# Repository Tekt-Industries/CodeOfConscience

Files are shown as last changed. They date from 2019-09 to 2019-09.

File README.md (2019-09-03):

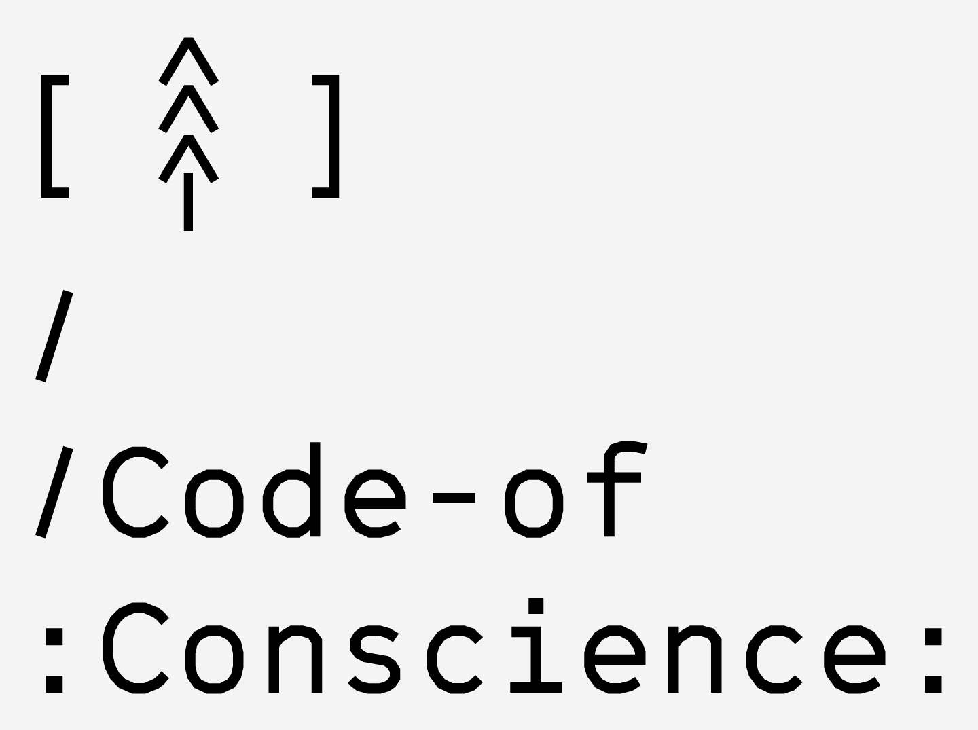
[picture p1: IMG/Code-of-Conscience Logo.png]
Tekt Industries


License (https://www.gnu.org/licenses/gpl-2.0.html)

## Summary

The Code of Conscience hardware platform was created as a call-to-action for partners to co-develop a low-cost, mass-manufacturable asset tracking system, designed specifically for the heavy machinery industry, including earth-moving equipment. 

Asset tracking telemetry systems are not a new technology and can be found in some modern heavy machinery but we currently don't use the data from these systems to protect ecosystems or provide transparency around their use. Older machinery is also unlikely to include asset tracking technology and can therefore slip through the cracks.  

The hardware platform itself is a low-component count cellular and GPS enabled IoT gateway, designed around the Nordic Semiconductor nRF9160 module, created to help start finding solutions to the world-wide problem of deforestation by directly raising awareness through remote monitoring of earth moving machinery potentially working illegally within protected rainforest areas.

The works shared here provide the full collection of schematic and PCB design files intended as a starting point for those individuals and organisations who wish to build smart devices that can ultimately be used to track and prevent rain-forest harvest and destruction outside the designated areas. 

These open-source designs can also be extended and customised to do more than asset tracking. For instance, the platform could be modified to detect fire within the worlds protected forests as an early warning system.

We encourage you to take up this call-to-action and create technology that changes our world for the better. 

## License

This documentation contains information which is provided AS IS, without attribution of liability or warranty under the GNU GPL v2.0 License - Open Source and permissive for commercial use, modification, distribution, and private use.

## Contributors

A dedicated team of engineers at [Tekt Industries](https://www.tektindustries.com), an international product design house based in  Melbourne, Australia brought together their years of experience within the IoT hardware development space to help create the initial hardware platform so that it may be shared with the world and grow from here.

We have been inspired by [AKQA](https://www.akqa.com), who heralded the call to action, crafted sample code, and provided the basis for the graphics that adorn the hardware platform.

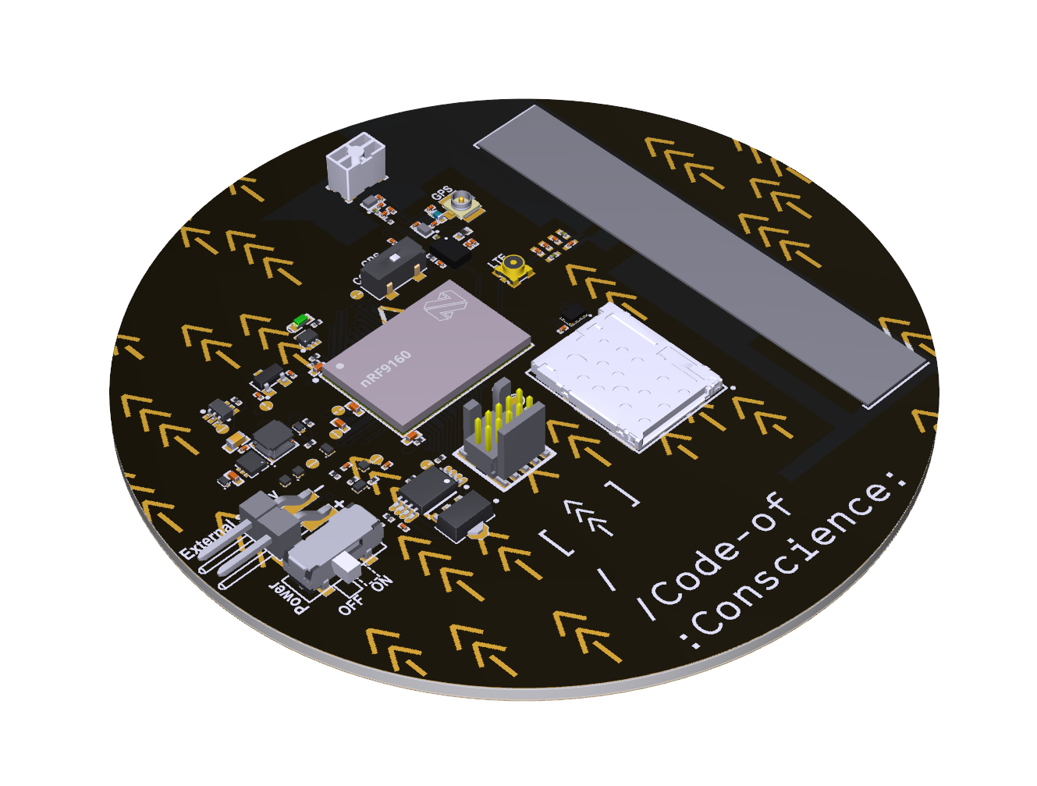
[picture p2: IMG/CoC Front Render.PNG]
PCB


[PCB]: https://github.com/Tekt-Industries/CodeOfConscience/blob/master/IMG/CoC%20Front%20Render.PNG "Tekt Industries"

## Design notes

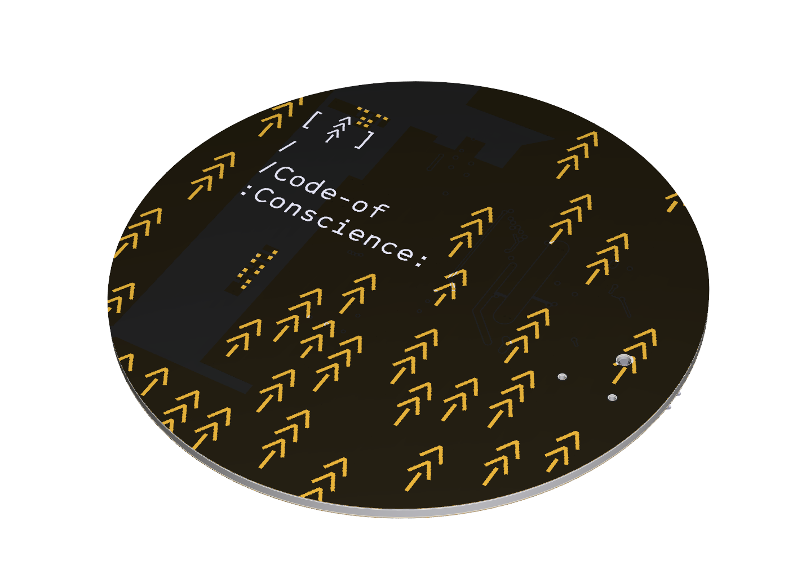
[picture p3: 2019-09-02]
IMG/CoC Back Render.PNG

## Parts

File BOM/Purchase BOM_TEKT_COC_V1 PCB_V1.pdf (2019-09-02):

| | Purchase BOM Source Data From: | | TEKT_COC_V1 PCB.PrjPCB | | | Note:
| | Project: | | TEKT_CoC_V1
| | Variant: | | None
| | Report Date: | 2/09/2019 | 5:41 PM
| | Print Date: | 02-Sep-19 | 6:32:28 PM
Quantity | Designator | Value | Comment | Description | Manufacturer | Manufacturer Part No. | Supplier | Supplier Part No. | Footprint | Reference
1 | A1 | 1462350001 | 1462350001 | ANTENNA MOLDED 1.575GHZ GPS | Molex | 1462350001 | Digi-Key | WM15009CT-ND | 1462350001 | TEKT_CoC_V1: A1
1 | A2 | P822601 | P822601 | ANTENNA PRESTTA OCTABAND LTE | Ethertronics | P822601 | Digi-Key | 939-1057-1-ND | P822601 | TEKT_CoC_V1: A2
4 | C1, C9, C15, C23 | 100pF | 100pF | Capacitor, NP0, ±2% | Murata Electronics North America | GRM0335C1E101JA01D | Digi-Key | 490-3160-1-ND | CAPC0603X03L_C | TEKT_CoC_V1: C1, C9, C15, C23
6 | C2, C8, C16, C21, C25, C26 | 100nF | 100nF | Capacitor, X5R, ±10% | Murata Electronics North America | GRM033R61C104KE84D | Digi-Key | 490-9985-1-ND | CAPC0603X03L_C | TEKT_CoC_V1: C2, C8, C16, C21, C25, C26
2 | C3, C4 | 39pF | 39pF | Chip Cap 0201 | Murata Electronics North America | GRM0335C1H390JA01D | Digi-Key | 490-11326-1-ND | CAPC0603X03L_C | TEKT_CoC_V1: C3, C4
5 | C5, C17, C18, C19, C22 | 4.7µF | 4.7µF | Capacitor, X5R, ±20% | Murata Electronics North America | ZRB15XR61A475KE01D | Digi-Key | 490-13252-1-ND | CAPC1005X04L | TEKT_CoC_V1: C5, C17, C18, C19, C22
1 | C6 | 4.7pF | 4.7pF | Chip Cap 0201 | Murata Electronics North America | GRM0335C1H4R7CA01D | Digi-Key | 490-6130-1-ND | CAPC0603X03L_C | TEKT_CoC_V1: C6
4 | C7, C12, C13, C14 | N.C. | N.C. | Not mounted | | | | | CAPC0603X03L_C | TEKT_CoC_V1: C7, C12, C13, C14
1 | C10 | 3.5pF | 3.5pF | Chip Cap 0201 | Taiyo Yuden | UMK063CG3R5CTHF | Digi-Key | 587-5326-1-ND | CAPC0603X03L_C | TEKT_CoC_V1: C10
1 | C11 | 33pF | 33pF | Chip Cap 0201 | Murata Electronics North America | GRM0335C1H330JA01D | Digi-Key | 490-6126-1-ND | CAPC0603X03L_C | TEKT_CoC_V1: C11
1 | C20 | 10nF | 10nF | Capacitor, X7R, ±10% | Murata Electronics North America | GRM033R61E103KA12D | Digi-Key | 490-7194-1-ND | CAPC0603X03L_C | TEKT_CoC_V1: C20
1 | C24 | 10µF | 10µF | Capacitor, 0603, 25V, X5R | Murata Electronics North America | ZRB18AR61E106ME01L | Digi-Key | 490-10991-1-ND | CAPC1608X06L | TEKT_CoC_V1: C24
2 | C27, C28 | 1.0µF | 1.0µF | Capacitor, X5R, ±10% | Samsung Electro-Mechanics | CL03A105KP3NSNC | Digi-Key | 1276-6795-1-ND | CAPC0603X03L_C | TEKT_CoC_V1: C27, C28
1 | D1 | CM1402 | CM1402 | EMI Network Filter Arrays SIM CARD EMI FILTER WITH ESD PROTECTION | ON Semiconductor | CM1402-03CP | Digi-Key | CM1402-03CPOSTR-ND | CM1402 | TEKT_CoC_V1: D1
2 | D2, D3 | NSR0620P2T5G | NSR0620P2T5G | 20V schottky barrier diode, Vf 350 mV @ 100 mA, Ir 2.0 µA @ 10 V, If 500 mA | ON Semiconductor | NSR0620P2T5G | Digi-Key | NSR0620P2T5GOSCT-ND | SODFL100X40-2N | TEKT_CoC_V1: D2, D3
1 | J1 | MM8130-2600 | MM8130-2600 | Coaxial Connector with Switch | Murata | MM8130-2600 | Digi-Key | 490-4981-1-ND | COAXIAL-SWF | TEKT_CoC_V1: J1
1 | J2 | SF72S006VBAR250
| | 0 | SF72S006VBAR2500 | n 8 (6 + 2) Position Card Connector NANO SIM Surface Mount, Right Angle Gold | JAE | SF72S006VBAR2500 | Digi-Key | 670-2799-1-ND | SF72S006VBAR2500 | TEKT_CoC_V1: J2
1 | L1 | 68nH | 68nH | Chip Inductor | Murata Electronics North America | LQG15HS68NJ02D | Digi-Key | 490-2633-1-ND | INDC1005X04L | TEKT_CoC_V1: L1
1 | L2 | 5.6nH | 5.6nH | Chip Inductor | Murata Electronics North America | LQP03TN5N6H02D | Digi-Key | 490-6734-1-ND | INDC0603X03L_C | TEKT_CoC_V1: L2
1 | L3 | 3.3nH | 3.3nH | Chip Inductor | Murata Electronics North America | LQP03TN3N3B02D | Digi-Key | 490-6728-1-ND | INDC0603X03L_C | TEKT_CoC_V1: L3
1 | L4 | 6.8nH | 6.8nH | Chip Inductor | Murata Electronics North America | LQP03TN6N8J02D | Digi-Key | 490-5564-1-ND | INDC0603X03L_C | TEKT_CoC_V1: L4
1 | L5 | 1.5nH | 1.5nH | Chip Inductor | Murata Electronics North America | LQP03TG1N5B02D | Digi-Key | 490-14701-1-ND | INDC0603X03L_C | TEKT_CoC_V1: L5
1 | L6 | 22nH | 22nH | Chip Inductor | Taiyo Yuden | HKQ0603W22NH-T | Digi-Key | 587-4663-1-ND | INDC0603X03L_C | TEKT_CoC_V1: L6
1 | L7 | 4.7µH | 4.7µH | Ferrite Inductor, Shielded, 1,04A, 144mOhm | Taiyo Yuden | NR3015T4R7M | Digi-Key | 587-1649-1-ND | TY-NR3015 | TEKT_CoC_V1: L7
1 | LED1 | L0603G | L0603G | LED, Green, 0603, 570nm, Vf=1.7V, 2.24..5.6mcd, - 40 to +100°C | Osram | LG L29K-G2J1-24-Z | Digi-Key | 475-2709-1-ND | LED_0603_G | TEKT_CoC_V1: LED1
1 | M1 | nRF9160 DEV2 | nRF9160 DEV2 | nRF9160 MODULE, SiP LGA | Nordic Semiconductor ASA | NRF9160-SICA | Digi-Key | 1490-1074-1-ND | nRF9160_DEV2_MO DULE | TEKT_CoC_V1: M1
1 | P1 | U.FL-R-SMT-1 | U.FL-R-SMT-1 | ONN U.FL RCPT STR 50 OHM SMD | Hirose Electric Co Ltd | U.FL-R-SMT-1 | Digi-Key | H11891DKR-ND | COAXIAL RF U.FL-R- SMT-1 | TEKT_CoC_V1: P1
1 | P2 | Pin Header 2x5, 1.27mm | Pin Header 2x5, 1.27mm | Pin Header 2x5, 1.27mm (50mil), SMD, Keying Shroud | Samtec Inc. | FTSH-105-01-F-DV-K-TR | Digi-Key | SAM13160CT-ND | HDR_2x5-SMD- 1.27mm-K | TEKT_CoC_V1: P2
1 | P3 | Pin List 1x2, Angled | Pin List 1x2, Angled | Pin List 1x2, 2.54mm (100mil), Right Angled, SMD | Samtec Inc. | TSM-102-01-L-SH-A | Digi-Key | SAM10266-ND | LIST_ANG_1x2-SMD- 2.54MM | TEKT_CoC_V1: P3
1 | Q1 | FDG6321C | FDG6321C | Fairchild, FDG6321C, Dual N & P Channel Digital FET | Fairchild | FDG6321C | Digi-Key | FDG6321CCT-ND | SOT65P210X100-6N | TEKT_CoC_V1: Q1
1 | Q2 | NX3020NAKV | NX3020NAKV | MOSFET 2N-CH 30V 0.2A SOT666 | Nexperia | NX3020NAKV,115 | Digi-Key | 1727-1287-2-ND | NX3020NAKV | TEKT_CoC_V1: Q2
1 | Q3 | FCX690BTA | FCX690BTA | 45V NPN high gain power transistor | Diodes Incorporated | FCX690BTA | Digi-Key | FCX690BCT-ND | SOT89-150P409X160- 3N | TEKT_CoC_V1: Q3
2 | Q4, Q5 | RV2C010UNT2L | RV2C010UNT2L | N-Channel MOSFET, 20V, 1A, 470mOhm, 400mW | Rohm Semiconductor | RV2C010UNT2L | Digi-Key | RV2C010UNT2LCT-ND | DFN65P100X40-3L | TEKT_CoC_V1: Q4, Q5
1 | R1 | 0R | 0R | Resistor, ±5%, 0.063W | Stackpole Electronics Inc | RMCF0402ZT0R00 | Digi-Key | RMCF0402ZT0R00CT-ND | RESC1005X04L | TEKT_CoC_V1: R1
1 | R2 | 10k | 10k | Resistor, ±1%, 0.05W | Samsung Electro-Mechanics | RC0603F103CS | Digi-Key | 1276-3670-1-ND | RESC0603X03L_C | TEKT_CoC_V1: R2
3 | R3, R4, R6 | 0R | 0R | Resistor, ±5%, 0.05W | Yageo | RC0201JR-070RL | Digi-Key | 311-0.0NCT-ND | RESC0603X03L_C | TEKT_CoC_V1: R3, R4, R6
1 | R5 | 3k | 3k | Resistor, ±1%, 0.05W | Yageo | RC0201FR-073KL | Digi-Key | YAG2656CT-ND | RESC0603X03L_C | TEKT_CoC_V1: R5
2 | R7, R13 | 150k | 150k | Resistor, ±1%, 0.05W | Stackpole Electronics Inc | RMCF0201FT150K | Digi-Key | RMCF0201FT150KCT-ND | RESC0603X03L_C | TEKT_CoC_V1: R7, R13
2 | R8, R14 | 1M0 | 1M0 | Resistor, ±1%, 0.05W | Yageo | RC0201FR-071ML | Digi-Key | 311-1MMCT-ND | RESC0603X03L_C | TEKT_CoC_V1: R8, R14
1 | R9 | 47k | 47k | Resistor, ±1%, 0.05W | Samsung Electro-Mechanics | RC0603F473CS | Digi-Key | 1276-3701-1-ND | RESC0603X03L_C | TEKT_CoC_V1: R9
1 | R10 | 68R | 68R | Resistor, ±1%, 0.05W | Yageo | RC0201FR-0768RL | Digi-Key | YAG2773CT-ND | RESC0603X03L_C | TEKT_CoC_V1: R10
1 | R11 | 120k | 120k | Resistor, ±1%, 0.05W | Yageo | RC0201FR-07120KL | Digi-Key | 311-120KMCT-ND | RESC0603X03L_C | TEKT_CoC_V1: R11
1 | R12 | 100k | 100k | Resistor, ±1%, 0.05W | Yageo | RC0201FR-07100KL | Digi-Key | 311-100KMCT-ND | RESC0603X03L_C | TEKT_CoC_V1: R12

### Each component is grouped by Manufacturer Part No. and Load column, so it is possible for a single part number to be in multiple rows. Please ensure DNP parts in "Load" column are not

Quantity | Designator | Value | Comment | Description | Manufacturer | Manufacturer Part No. | Supplier | Supplier Part No. | Footprint | Reference
3 | R15, R16, R18 | 10M | 10M | Resistor, ±1%, 0.05W | KOA Speer Electronics, Inc. | RK73H1HTTC1005F | Digi-Key | 2019-RK73H1HTTC1005FCT- ND | RESC0603X03L_C | TEKT_CoC_V1: R15, R16, R18
1 | R17 | 1k | 1k | Resistor, ±1%, 0.05W | Yageo | RC0201FR-071KL | Digi-Key | 311-1KMCT-ND | RESC0603X03L_C | TEKT_CoC_V1: R17
1 | SW1 | Switch | Switch | SMD slide Switch (ON-ON) | Copal Electronics Inc | CJS-1200TA | Digi-Key | 563-1021-2-ND | CJS-120xA | TEKT_CoC_V1: SW1
1 | SW2 | Switch | Switch | SMD slide Switch (ON-ON) | C&K Components | JS202011JAQN | Digi-Key | CKN10722CT-ND | Switch-Slide-RA-J- Lead-DPDT- 8.5x3.5mm | TEKT_CoC_V1: SW2
1 | U1 | QM14501 | QM14501 | GPS, GLONASS, and BeiDou Low
Noise Amplifier With Integrated Output SAW Filter, 1.55 to 1.61 GHz, 13.5 dB
Qorvo | QM14501 | Qorvo | QM14501 | QM14501 | TEKT_CoC_V1: U1
2 | U2, U3 | QM13132 | QM13132 | Single Pole Double Throw Switch | Qorvo | QM13132 | Qorvo | QM13132 | QM13132 | TEKT_CoC_V1: U2, U3
1 | U4 | XC9236 | XC9236 | 600mA Driver Transistor Built-In, Synchronous Step-Down DC/DC Converters | Torex Semiconductor | XC9236F08CER-G | Mouser | 865-XC9236F08CER-G | USP-6C | TEKT_CoC_V1: U4
3 | U5, U7, U8 | TCK106AG | TCK106AG | IC POWER DIST LOAD SWITCH
4WCSP
Toshiba | TCK106AG,LF | Digi-Key | TCK106AGLFTR-ND | TCK106AG | TEKT_CoC_V1: U5, U7, U8
1 | U6 | TS27L2IPT | TS27L2IPT | Precision very low power CMOS dual
operational amplifier
STMicroelectronics | TS27L2IPT | Digi-Key | 497-8085-1-ND | TSOP65P640X120- 8N | TEKT_CoC_V1: U6
1 | U9 | AP7333-33SAG-7 | AP7333-33SAG-7 | 300mA, Low Quiescent Current, Fast
Transient Low Dropout Linear Regulator
Diodes Incorporated | AP7333-33SAG-7 | Digi-Key | AP7333-33SAG-7DICT-ND | SOT-23A | TEKT_CoC_V1: U9

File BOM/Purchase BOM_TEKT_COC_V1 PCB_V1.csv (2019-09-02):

Quantity | Designator | Value | Comment | Description | Manufacturer | Manufacturer Part No. | Supplier | Supplier Part No. | Footprint
1 | A1 | 1462350001 | 1462350001 | ANTENNA MOLDED 1.575GHZ GPS | Molex | 1462350001 | Digi-Key | WM15009CT-ND | 1462350001
1 | A2 | P822601 | P822601 | ANTENNA PRESTTA OCTABAND LTE | Ethertronics | P822601 | Digi-Key | 939-1057-1-ND | P822601
4 | C1, C9, C15, C23 | 100pF | 100pF | Capacitor, NP0, ±2% | Murata Electronics North America | GRM0335C1E101JA01D | Digi-Key | 490-3160-1-ND | CAPC0603X03L_C
6 | C2, C8, C16, C21, C25, C26 | 100nF | 100nF | Capacitor, X5R, ±10% | Murata Electronics North America | GRM033R61C104KE84D | Digi-Key | 490-9985-1-ND | CAPC0603X03L_C
2 | C3, C4 | 39pF | 39pF | Chip Cap 0201 | Murata Electronics North America | GRM0335C1H390JA01D | Digi-Key | 490-11326-1-ND | CAPC0603X03L_C
5 | C5, C17, C18, C19, C22 | 4.7µF | 4.7µF | Capacitor, X5R, ±20% | Murata Electronics North America | ZRB15XR61A475KE01D | Digi-Key | 490-13252-1-ND | CAPC1005X04L
1 | C6 | 4.7pF | 4.7pF | Chip Cap 0201 | Murata Electronics North America | GRM0335C1H4R7CA01D | Digi-Key | 490-6130-1-ND | CAPC0603X03L_C
4 | C7, C12, C13, C14 | N.C. | N.C. | Not mounted |  |  |  |  | CAPC0603X03L_C
1 | C10 | 3.5pF | 3.5pF | Chip Cap 0201 | Taiyo Yuden | UMK063CG3R5CTHF | Digi-Key | 587-5326-1-ND | CAPC0603X03L_C
1 | C11 | 33pF | 33pF | Chip Cap 0201 | Murata Electronics North America | GRM0335C1H330JA01D | Digi-Key | 490-6126-1-ND | CAPC0603X03L_C
1 | C20 | 10nF | 10nF | Capacitor, X7R, ±10% | Murata Electronics North America | GRM033R61E103KA12D | Digi-Key | 490-7194-1-ND | CAPC0603X03L_C
1 | C24 | 10µF | 10µF | Capacitor, 0603, 25V, X5R | Murata Electronics North America | ZRB18AR61E106ME01L | Digi-Key | 490-10991-1-ND | CAPC1608X06L
2 | C27, C28 | 1.0µF | 1.0µF | Capacitor, X5R, ±10% | Samsung Electro-Mechanics | CL03A105KP3NSNC | Digi-Key | 1276-6795-1-ND | CAPC0603X03L_C
1 | D1 | CM1402 | CM1402 | EMI Network Filter Arrays SIM CARD EMI FILTER WITH ESD PROTECTION | ON Semiconductor | CM1402-03CP | Digi-Key | CM1402-03CPOSTR-ND | CM1402
2 | D2, D3 | NSR0620P2T5G | NSR0620P2T5G | 20V schottky barrier diode, Vf 350 mV @ 100 mA, Ir 2.0 µA @ 10 V, If 500 mA | ON Semiconductor | NSR0620P2T5G | Digi-Key | NSR0620P2T5GOSCT-ND | SODFL100X40-2N
1 | J1 | MM8130-2600 | MM8130-2600 | Coaxial Connector with Switch | Murata | MM8130-2600 | Digi-Key | 490-4981-1-ND | COAXIAL-SWF
1 | J2 | SF72S006VBAR2500 | SF72S006VBAR2500 | n 8 (6 + 2) Position Card Connector NANO SIM Surface Mount, Right Angle Gold | JAE | SF72S006VBAR2500 | Digi-Key | 670-2799-1-ND | SF72S006VBAR2500
1 | L1 | 68nH | 68nH | Chip Inductor | Murata Electronics North America | LQG15HS68NJ02D | Digi-Key | 490-2633-1-ND | INDC1005X04L
1 | L2 | 5.6nH | 5.6nH | Chip Inductor | Murata Electronics North America | LQP03TN5N6H02D | Digi-Key | 490-6734-1-ND | INDC0603X03L_C
1 | L3 | 3.3nH | 3.3nH | Chip Inductor | Murata Electronics North America | LQP03TN3N3B02D | Digi-Key | 490-6728-1-ND | INDC0603X03L_C
1 | L4 | 6.8nH | 6.8nH | Chip Inductor | Murata Electronics North America | LQP03TN6N8J02D | Digi-Key | 490-5564-1-ND | INDC0603X03L_C
1 | L5 | 1.5nH | 1.5nH | Chip Inductor | Murata Electronics North America | LQP03TG1N5B02D | Digi-Key | 490-14701-1-ND | INDC0603X03L_C
1 | L6 | 22nH | 22nH | Chip Inductor | Taiyo Yuden | HKQ0603W22NH-T | Digi-Key | 587-4663-1-ND | INDC0603X03L_C
1 | L7 | 4.7µH | 4.7µH | Ferrite Inductor, Shielded, 1,04A, 144mOhm | Taiyo Yuden | NR3015T4R7M | Digi-Key | 587-1649-1-ND | TY-NR3015
1 | LED1 | L0603G | L0603G | LED, Green, 0603, 570nm, Vf=1.7V, 2.24..5.6mcd, - 40 to +100°C | Osram | LG L29K-G2J1-24-Z | Digi-Key | 475-2709-1-ND | LED_0603_G
1 | M1 | nRF9160 DEV2 | nRF9160 DEV2 | nRF9160 MODULE, SiP LGA | Nordic Semiconductor ASA | NRF9160-SICA | Digi-Key | 1490-1074-1-ND | nRF9160_DEV2_MODULE
1 | P1 | U.FL-R-SMT-1 | U.FL-R-SMT-1 | ONN U.FL RCPT STR 50 OHM SMD | Hirose Electric Co Ltd | U.FL-R-SMT-1 | Digi-Key | H11891DKR-ND | COAXIAL RF U.FL-R-SMT-1
1 | P2 | Pin Header 2x5, 1.27mm | Pin Header 2x5, 1.27mm | Pin Header 2x5, 1.27mm (50mil), SMD, Keying Shroud | Samtec Inc. | FTSH-105-01-F-DV-K-TR | Digi-Key | SAM13160CT-ND | HDR_2x5-SMD-1.27mm-K
1 | P3 | Pin List 1x2, Angled | Pin List 1x2, Angled | Pin List 1x2, 2.54mm (100mil), Right Angled, SMD | Samtec Inc. | TSM-102-01-L-SH-A | Digi-Key | SAM10266-ND | LIST_ANG_1x2-SMD-2.54MM
1 | Q1 | FDG6321C | FDG6321C | Fairchild, FDG6321C, Dual N & P Channel Digital FET | Fairchild | FDG6321C | Digi-Key | FDG6321CCT-ND | SOT65P210X100-6N
1 | Q2 | NX3020NAKV | NX3020NAKV | MOSFET 2N-CH 30V 0.2A SOT666 | Nexperia | NX3020NAKV,115 | Digi-Key | 1727-1287-2-ND | NX3020NAKV
1 | Q3 | FCX690BTA | FCX690BTA | 45V NPN high gain power transistor | Diodes Incorporated | FCX690BTA | Digi-Key | FCX690BCT-ND | SOT89-150P409X160-3N
2 | Q4, Q5 | RV2C010UNT2L | RV2C010UNT2L | N-Channel MOSFET, 20V, 1A, 470mOhm, 400mW | Rohm Semiconductor | RV2C010UNT2L | Digi-Key | RV2C010UNT2LCT-ND | DFN65P100X40-3L
1 | R1 | 0R | 0R | Resistor, ±5%, 0.063W | Stackpole Electronics Inc | RMCF0402ZT0R00 | Digi-Key | RMCF0402ZT0R00CT-ND | RESC1005X04L
1 | R2 | 10k | 10k | Resistor, ±1%, 0.05W | Samsung Electro-Mechanics | RC0603F103CS | Digi-Key | 1276-3670-1-ND | RESC0603X03L_C
3 | R3, R4, R6 | 0R | 0R | Resistor, ±5%, 0.05W | Yageo | RC0201JR-070RL | Digi-Key | 311-0.0NCT-ND | RESC0603X03L_C
1 | R5 | 3k | 3k | Resistor, ±1%, 0.05W | Yageo | RC0201FR-073KL | Digi-Key | YAG2656CT-ND | RESC0603X03L_C
2 | R7, R13 | 150k | 150k | Resistor, ±1%, 0.05W | Stackpole Electronics Inc | RMCF0201FT150K | Digi-Key | RMCF0201FT150KCT-ND | RESC0603X03L_C
2 | R8, R14 | 1M0 | 1M0 | Resistor, ±1%, 0.05W | Yageo | RC0201FR-071ML | Digi-Key | 311-1MMCT-ND | RESC0603X03L_C
1 | R9 | 47k | 47k | Resistor, ±1%, 0.05W | Samsung Electro-Mechanics | RC0603F473CS | Digi-Key | 1276-3701-1-ND | RESC0603X03L_C
1 | R10 | 68R | 68R | Resistor, ±1%, 0.05W | Yageo | RC0201FR-0768RL | Digi-Key | YAG2773CT-ND | RESC0603X03L_C
1 | R11 | 120k | 120k | Resistor, ±1%, 0.05W | Yageo | RC0201FR-07120KL | Digi-Key | 311-120KMCT-ND | RESC0603X03L_C
1 | R12 | 100k | 100k | Resistor, ±1%, 0.05W | Yageo | RC0201FR-07100KL | Digi-Key | 311-100KMCT-ND | RESC0603X03L_C
3 | R15, R16, R18 | 10M | 10M | Resistor, ±1%, 0.05W | KOA Speer Electronics, Inc. | RK73H1HTTC1005F | Digi-Key | 2019-RK73H1HTTC1005FCT-ND | RESC0603X03L_C
1 | R17 | 1k | 1k | Resistor, ±1%, 0.05W | Yageo | RC0201FR-071KL | Digi-Key | 311-1KMCT-ND | RESC0603X03L_C
1 | SW1 | Switch | Switch | SMD slide Switch (ON-ON) | Copal Electronics Inc | CJS-1200TA | Digi-Key | 563-1021-2-ND | CJS-120xA
1 | SW2 | Switch | Switch | SMD slide Switch (ON-ON) | C&K Components | JS202011JAQN | Digi-Key | CKN10722CT-ND | Switch-Slide-RA-J-Lead-DPDT-8.5x3.5mm
1 | U1 | QM14501 | QM14501 | GPS, GLONASS, and BeiDou Low Noise Amplifier With Integrated Output SAW Filter, 1.55 to 1.61 GHz, 13.5 dB | Qorvo | QM14501 | Qorvo | QM14501 | QM14501
2 | U2, U3 | QM13132 | QM13132 | Single Pole Double Throw Switch | Qorvo | QM13132 | Qorvo | QM13132 | QM13132
1 | U4 | XC9236 | XC9236 | 600mA Driver Transistor Built-In, Synchronous Step-Down DC/DC Converters | Torex Semiconductor | XC9236F08CER-G | Mouser | 865-XC9236F08CER-G | USP-6C
3 | U5, U7, U8 | TCK106AG | TCK106AG | IC POWER DIST LOAD SWITCH 4WCSP | Toshiba | TCK106AG,LF | Digi-Key | TCK106AGLFTR-ND | TCK106AG
1 | U6 | TS27L2IPT | TS27L2IPT | Precision very low power CMOS dual operational amplifier | STMicroelectronics | TS27L2IPT | Digi-Key | 497-8085-1-ND | TSOP65P640X120-8N
1 | U9 | AP7333-33SAG-7 | AP7333-33SAG-7 | 300mA, Low Quiescent Current, Fast Transient Low Dropout Linear Regulator | Diodes Incorporated | AP7333-33SAG-7 | Digi-Key | AP7333-33SAG-7DICT-ND | SOT-23A

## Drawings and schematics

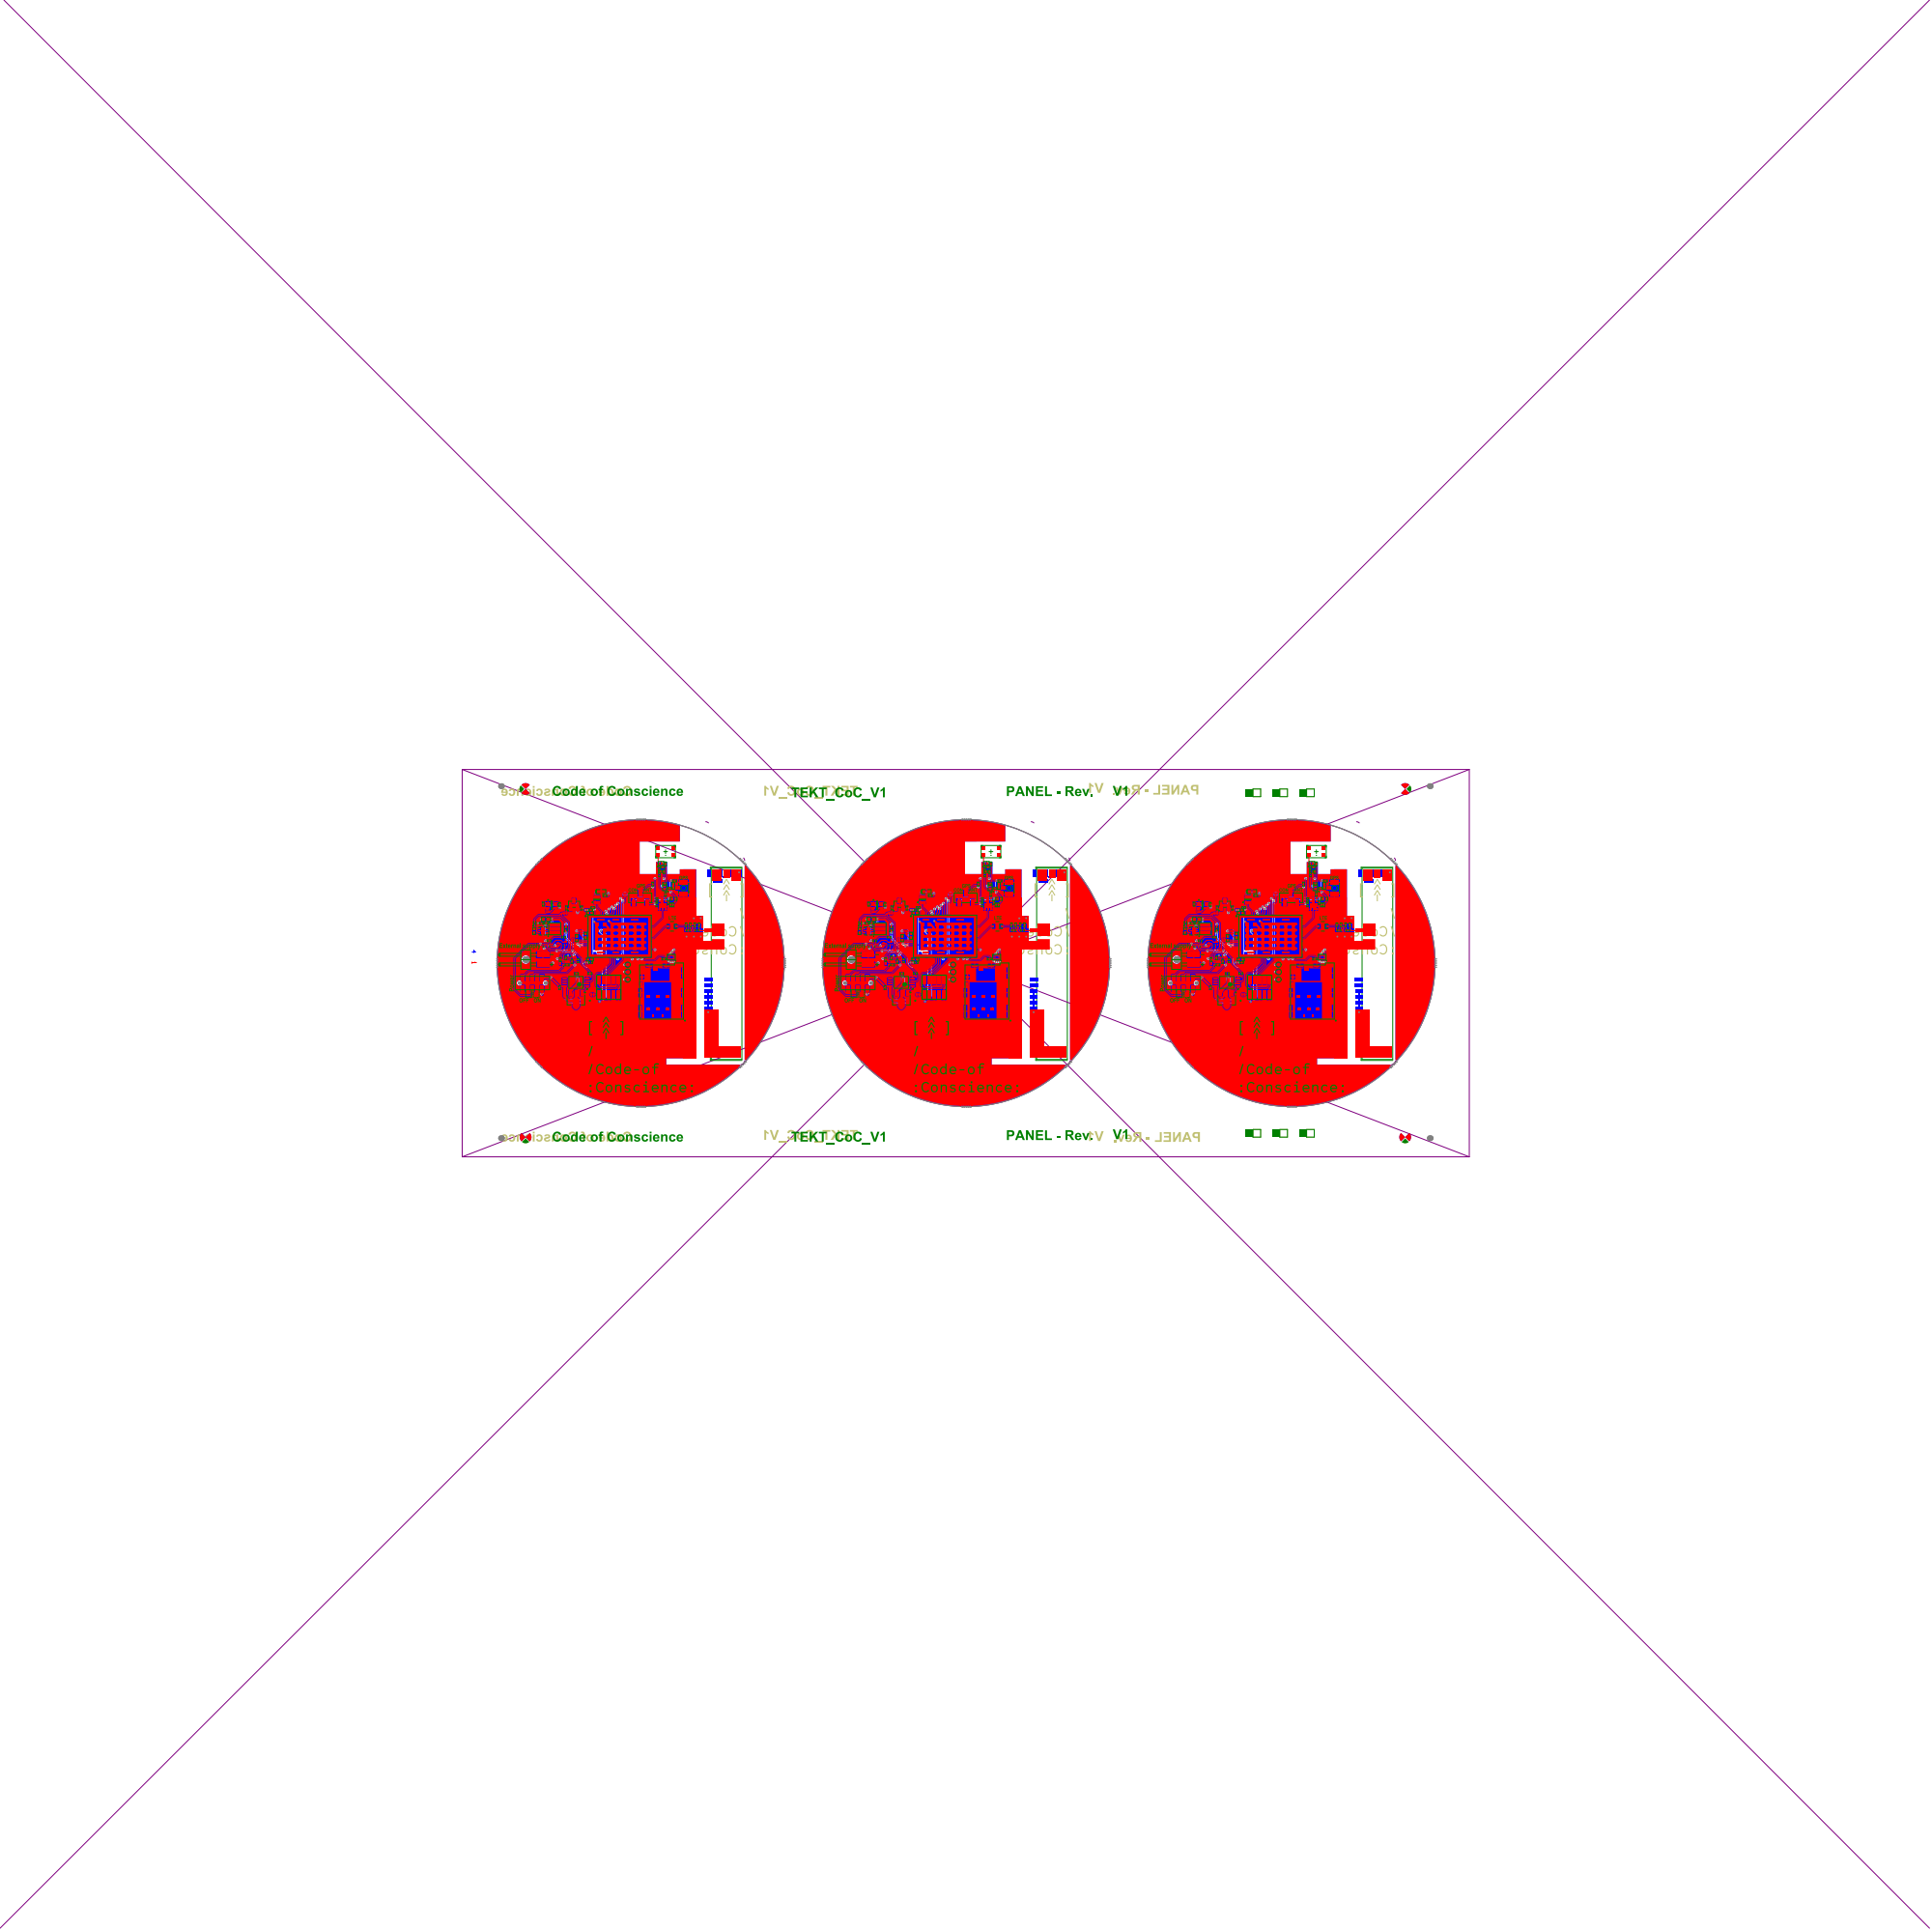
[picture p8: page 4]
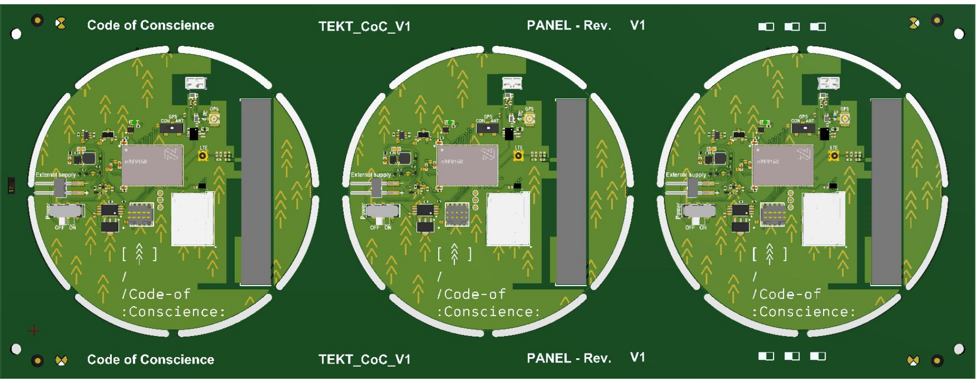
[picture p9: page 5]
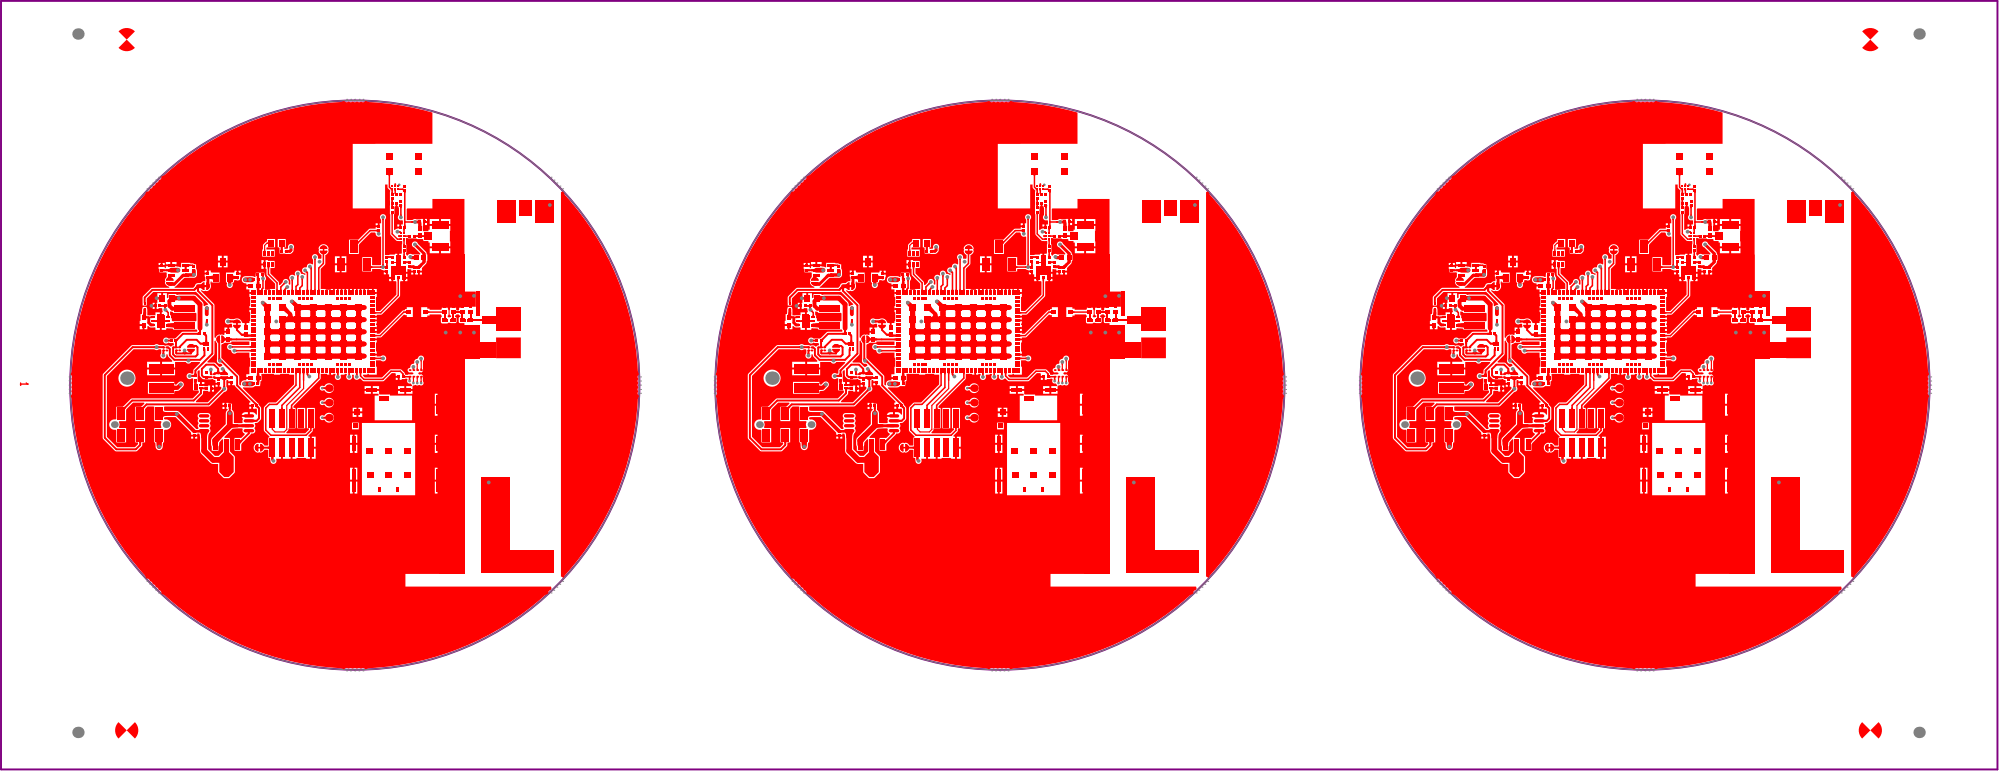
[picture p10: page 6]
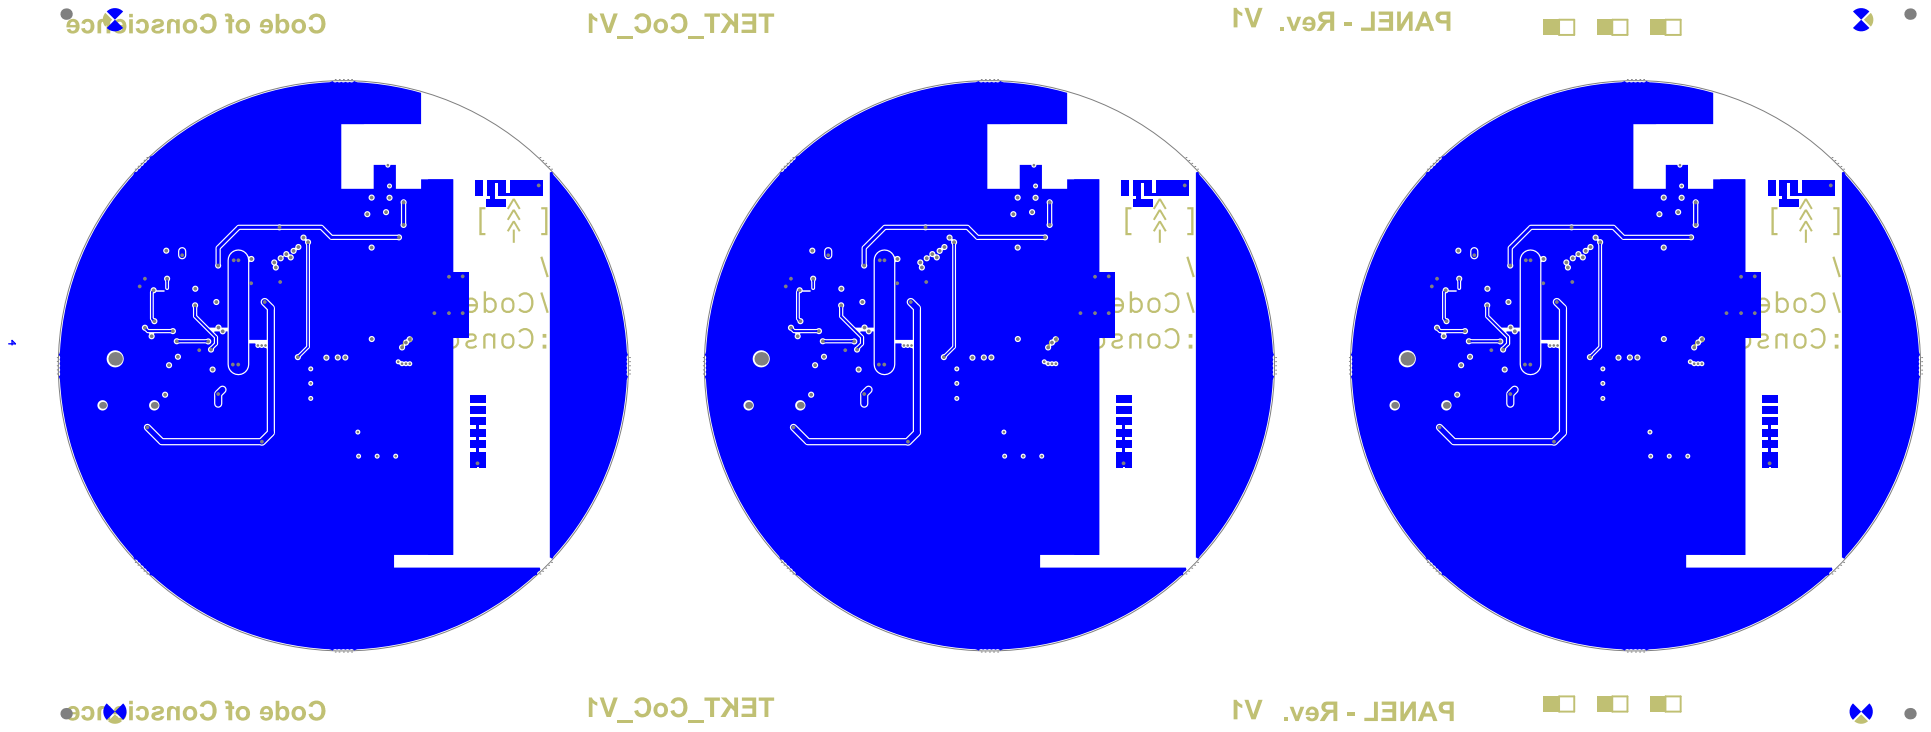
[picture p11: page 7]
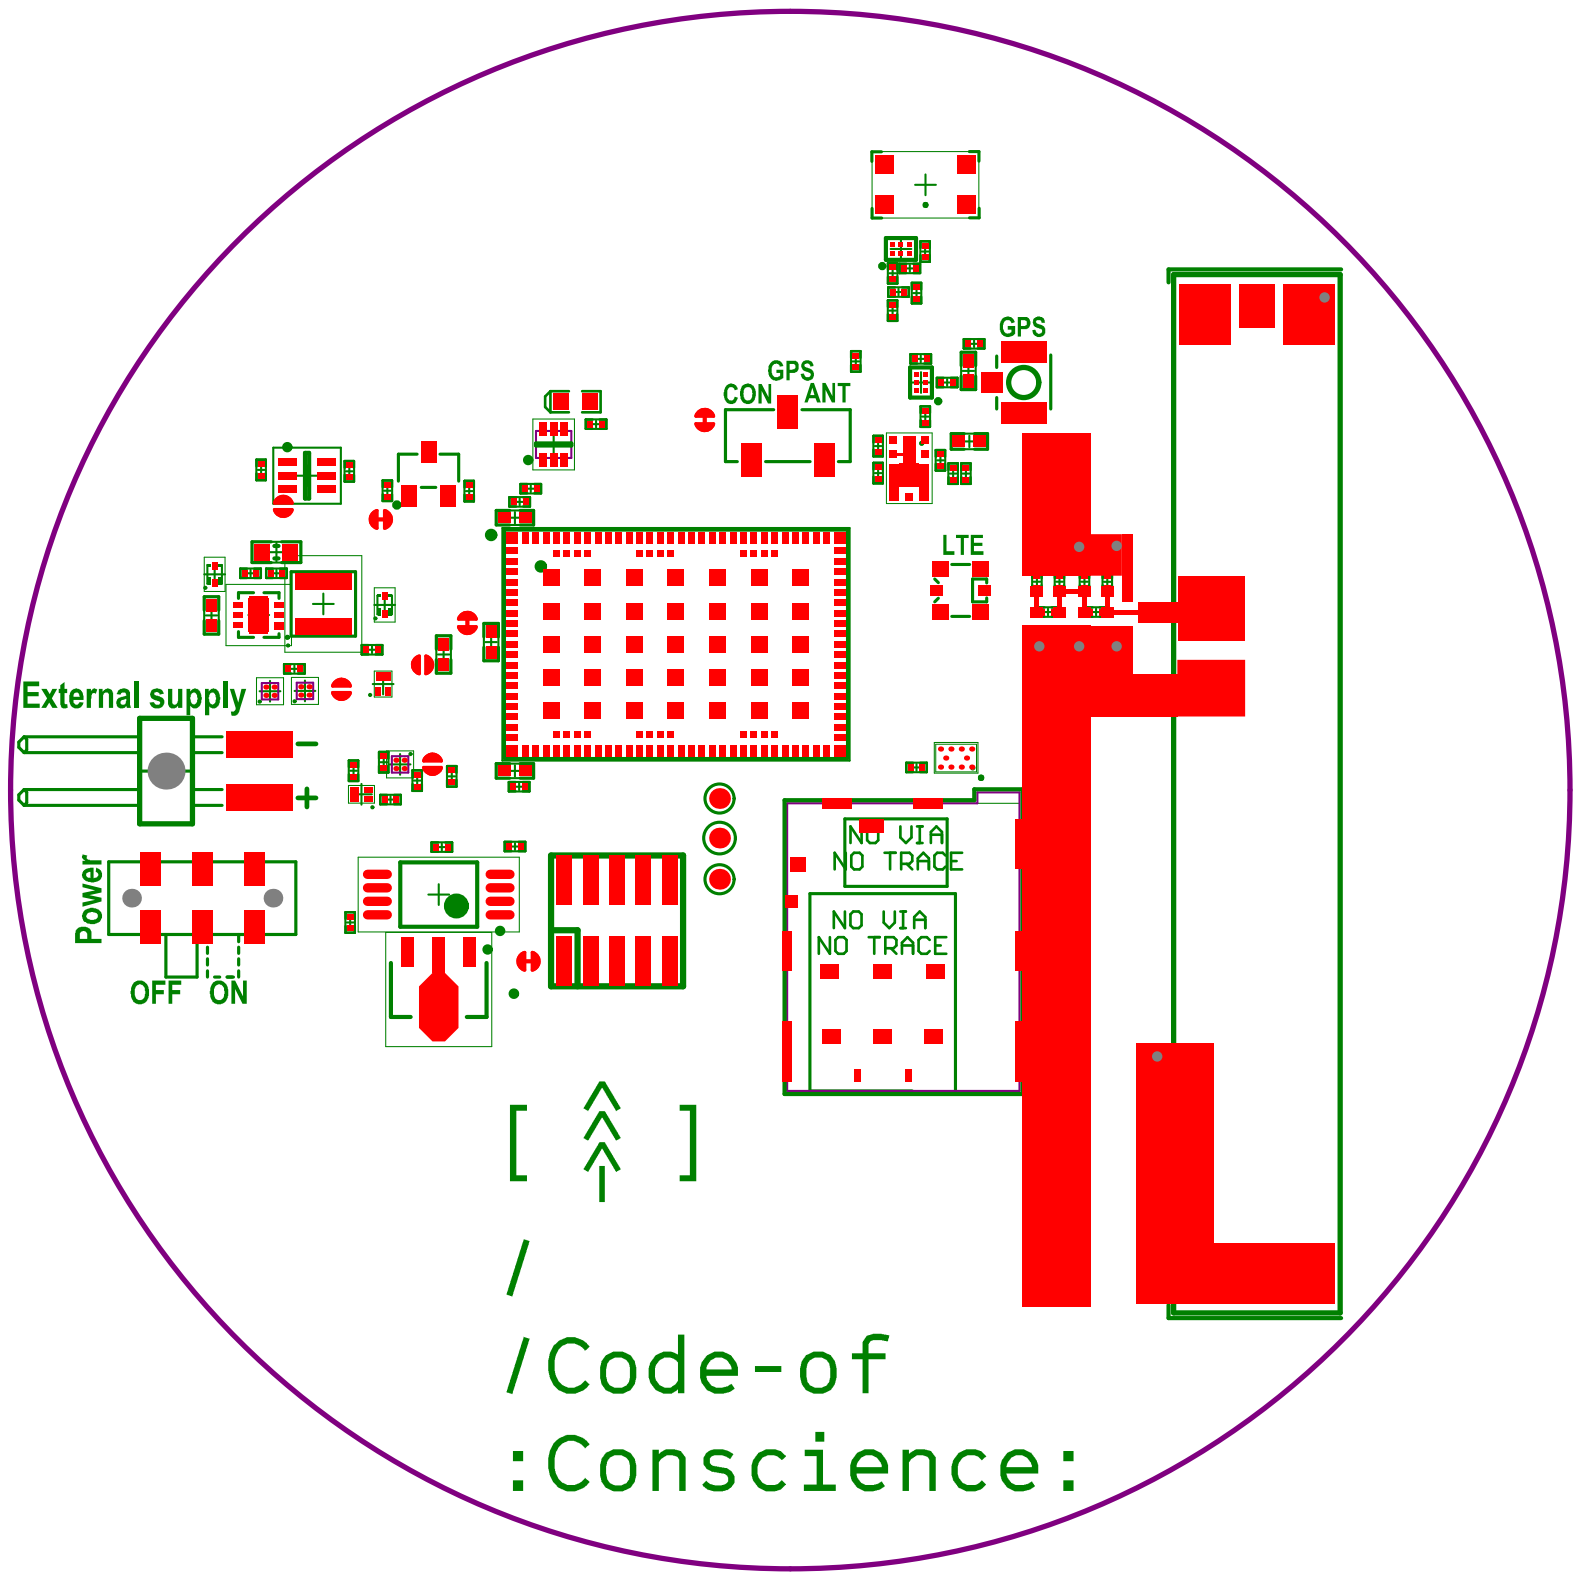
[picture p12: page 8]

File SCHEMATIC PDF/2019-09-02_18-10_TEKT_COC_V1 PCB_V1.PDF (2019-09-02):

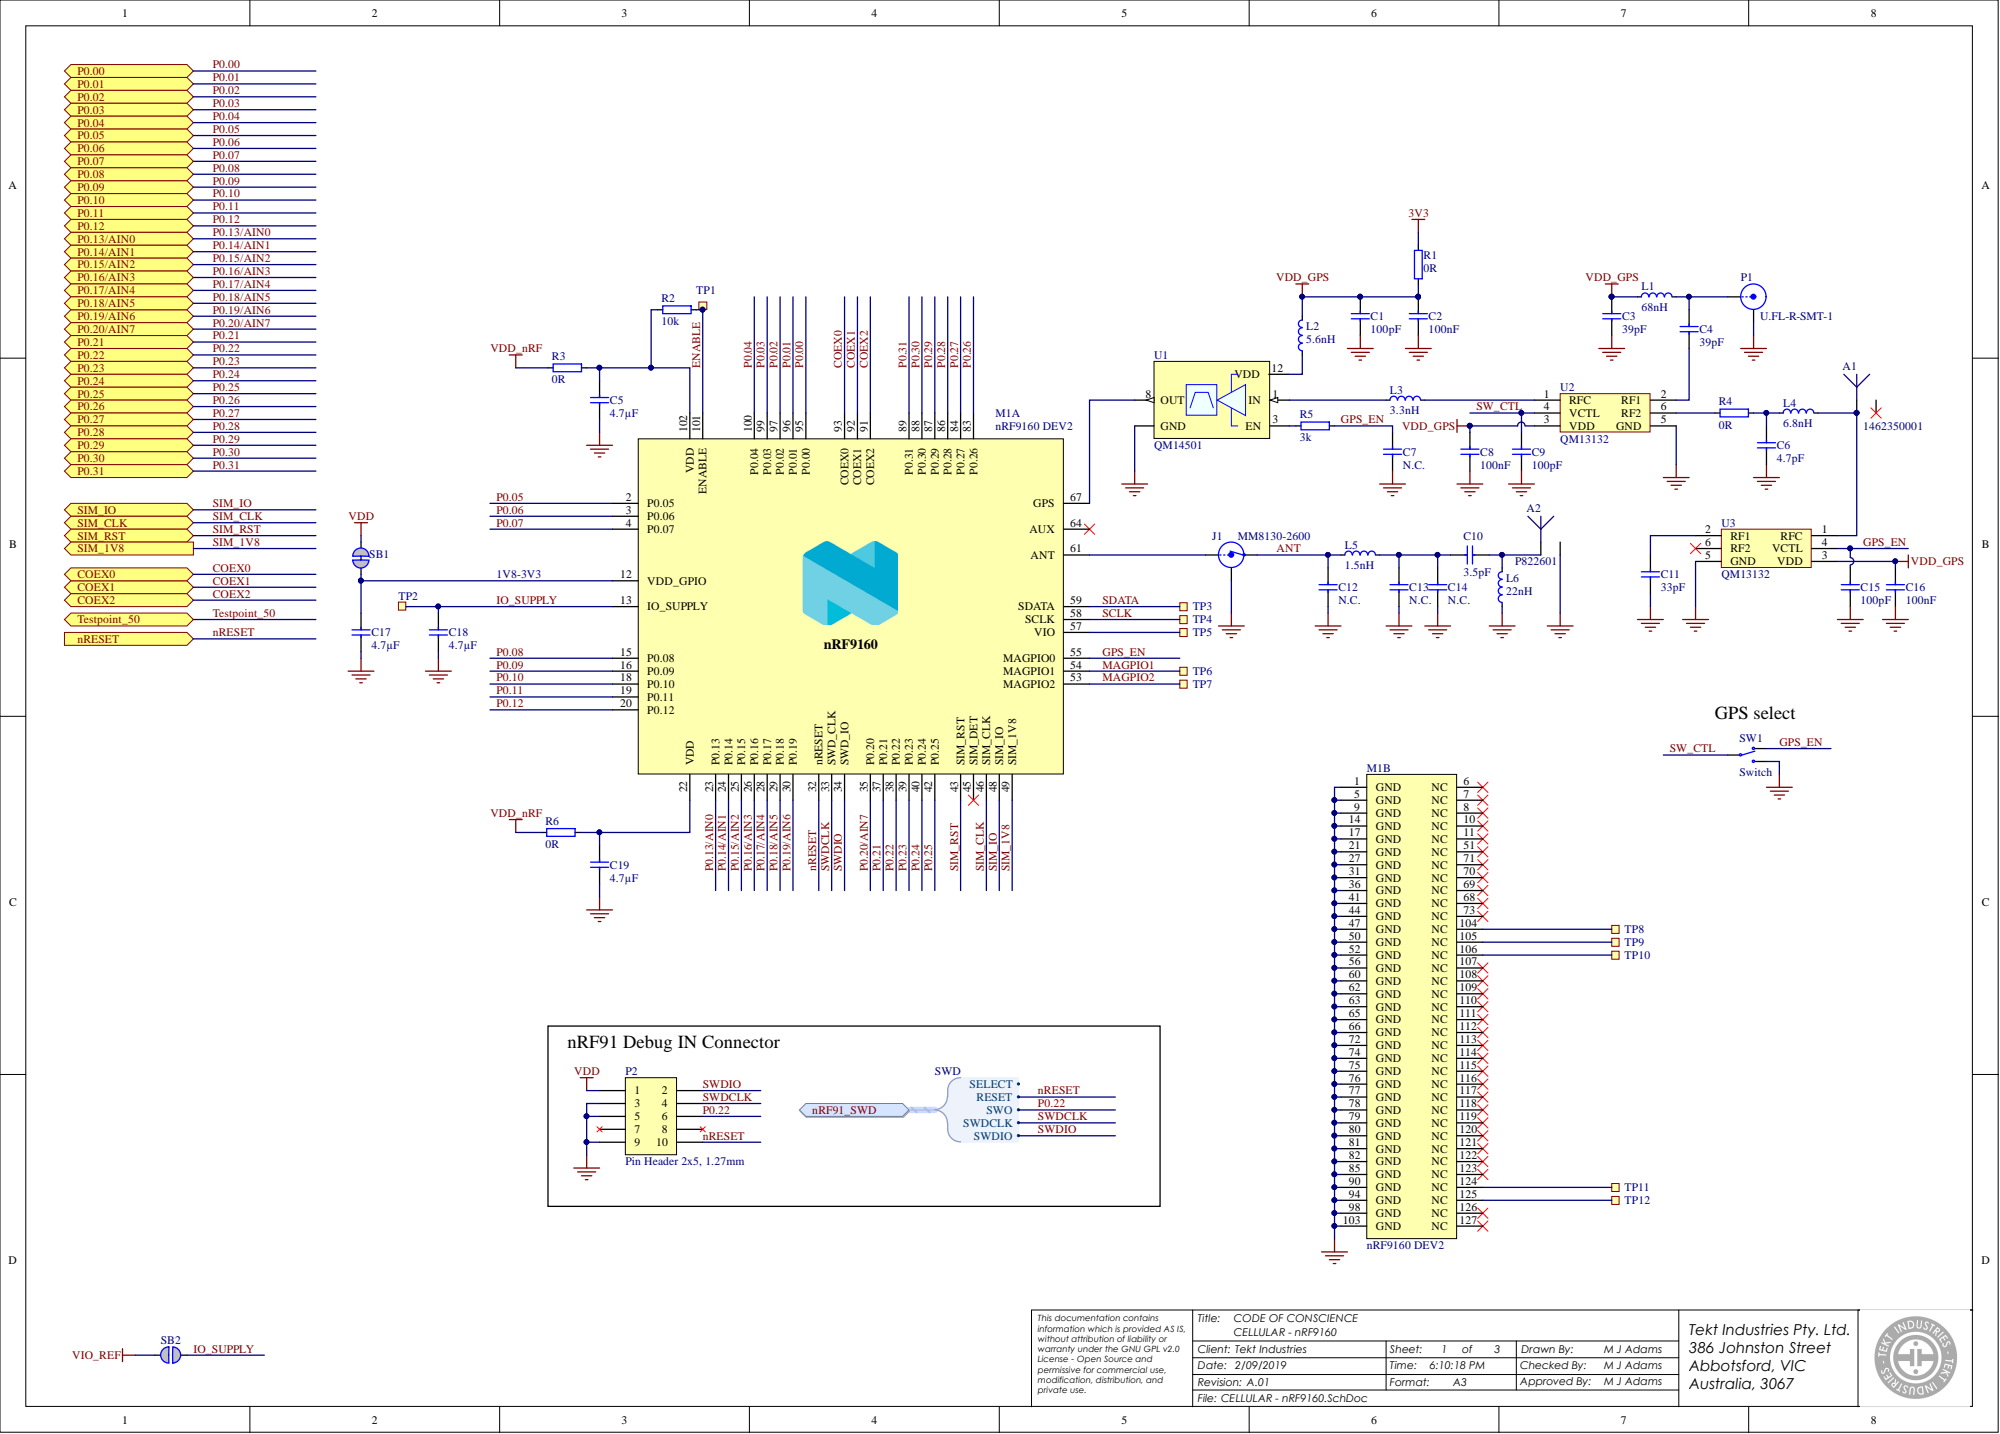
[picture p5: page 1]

This documentation contains information which is provided AS IS, without attribution of liability or warranty under the GNU GPL v2.0 License - Open Source and permissive for commercial use, modification, distribution, and private use. | Title: CODE OF CONSCIENCE CELLULAR - nRF9160 | Tekt Industries Pty. Ltd. 386 Johnston Street Abbotsford, VIC Australia, 3067

Client: Tekt Industries | Sheet: 1 of 3 | Drawn By: M J Adams
Date: 2/09/2019 | Time: 6:10:18 PM | Checked By: M J Adams
Revision: A.01 | Format: A3 | Approved By: M J Adams

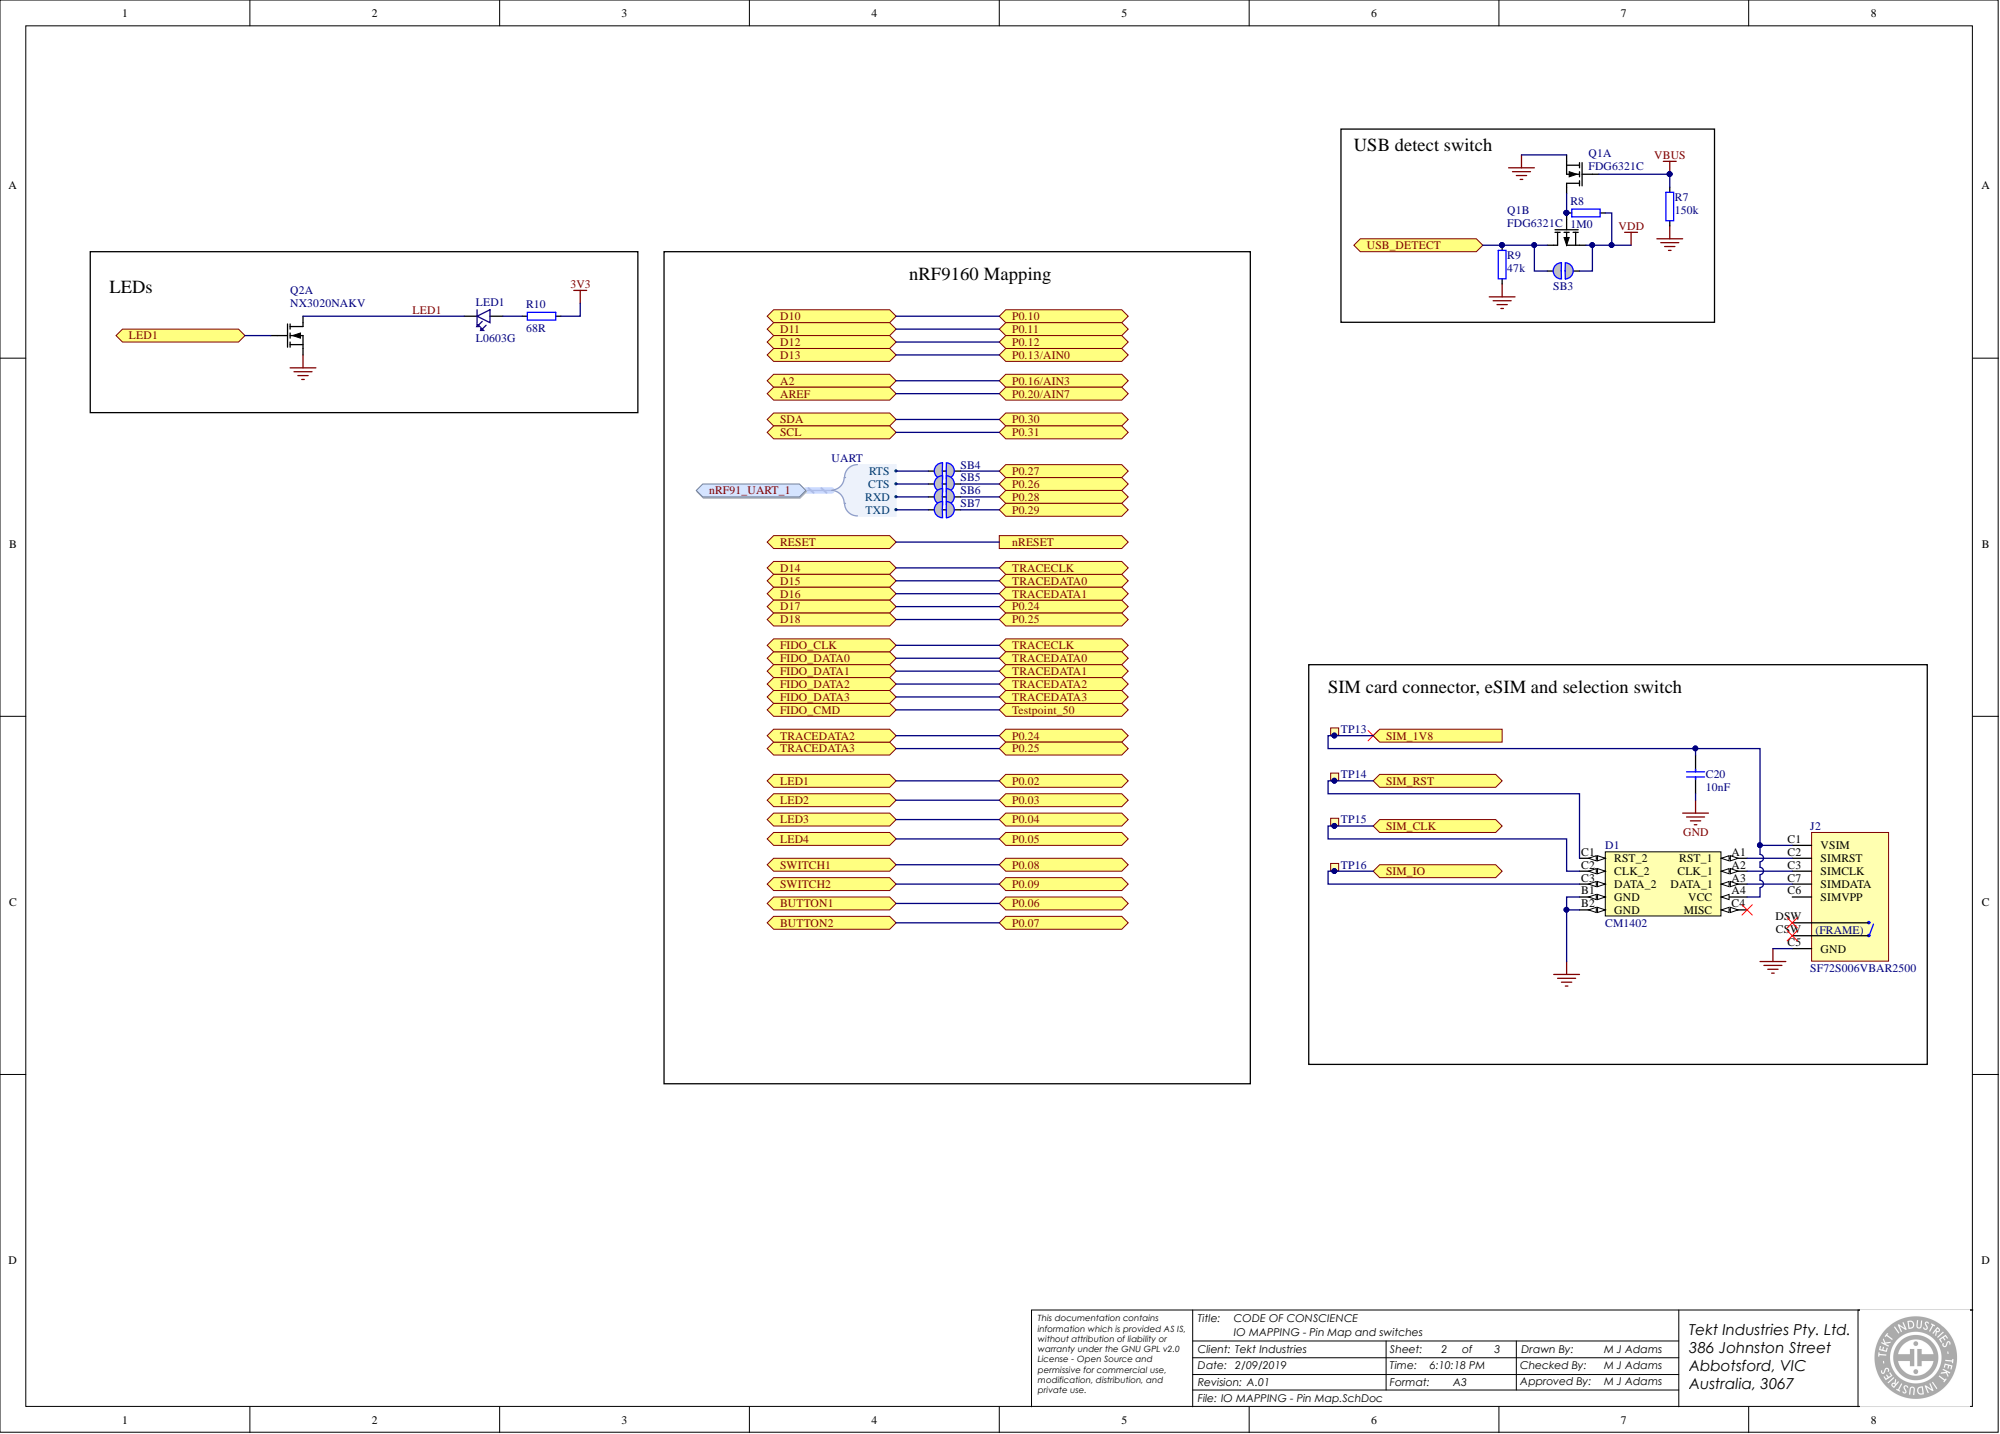
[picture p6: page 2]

This document a tion cont ains inform a tion which is provided AS IS, without a t tribution of lia bilit y or w arrant y under the G NU GPL v2.0 License -O pen Source and permis sive for com mercial use, modifica tion, dis tribution, and priva te use. | Title : C O D E OF C O N S C I E N C E I O MAPPI NG - Pin Map and switche s | Tekt Industries Pty. Ltd. 386 Johnston Street Abbotsford, VIC Australia, 3 0 6 7

Client : T e k t Indus t rie s | She e t : 2 o f 3 | D rawn B y : M J Adam s
Dat e : 2/09/2019 | Tim e : 6:10:18 PM | Check ed B y : M J Adam s
Revision: A.01 | Fo r mat : A 3 | Appr oved B y : M J Adam s

NG - Pin Map.SchD

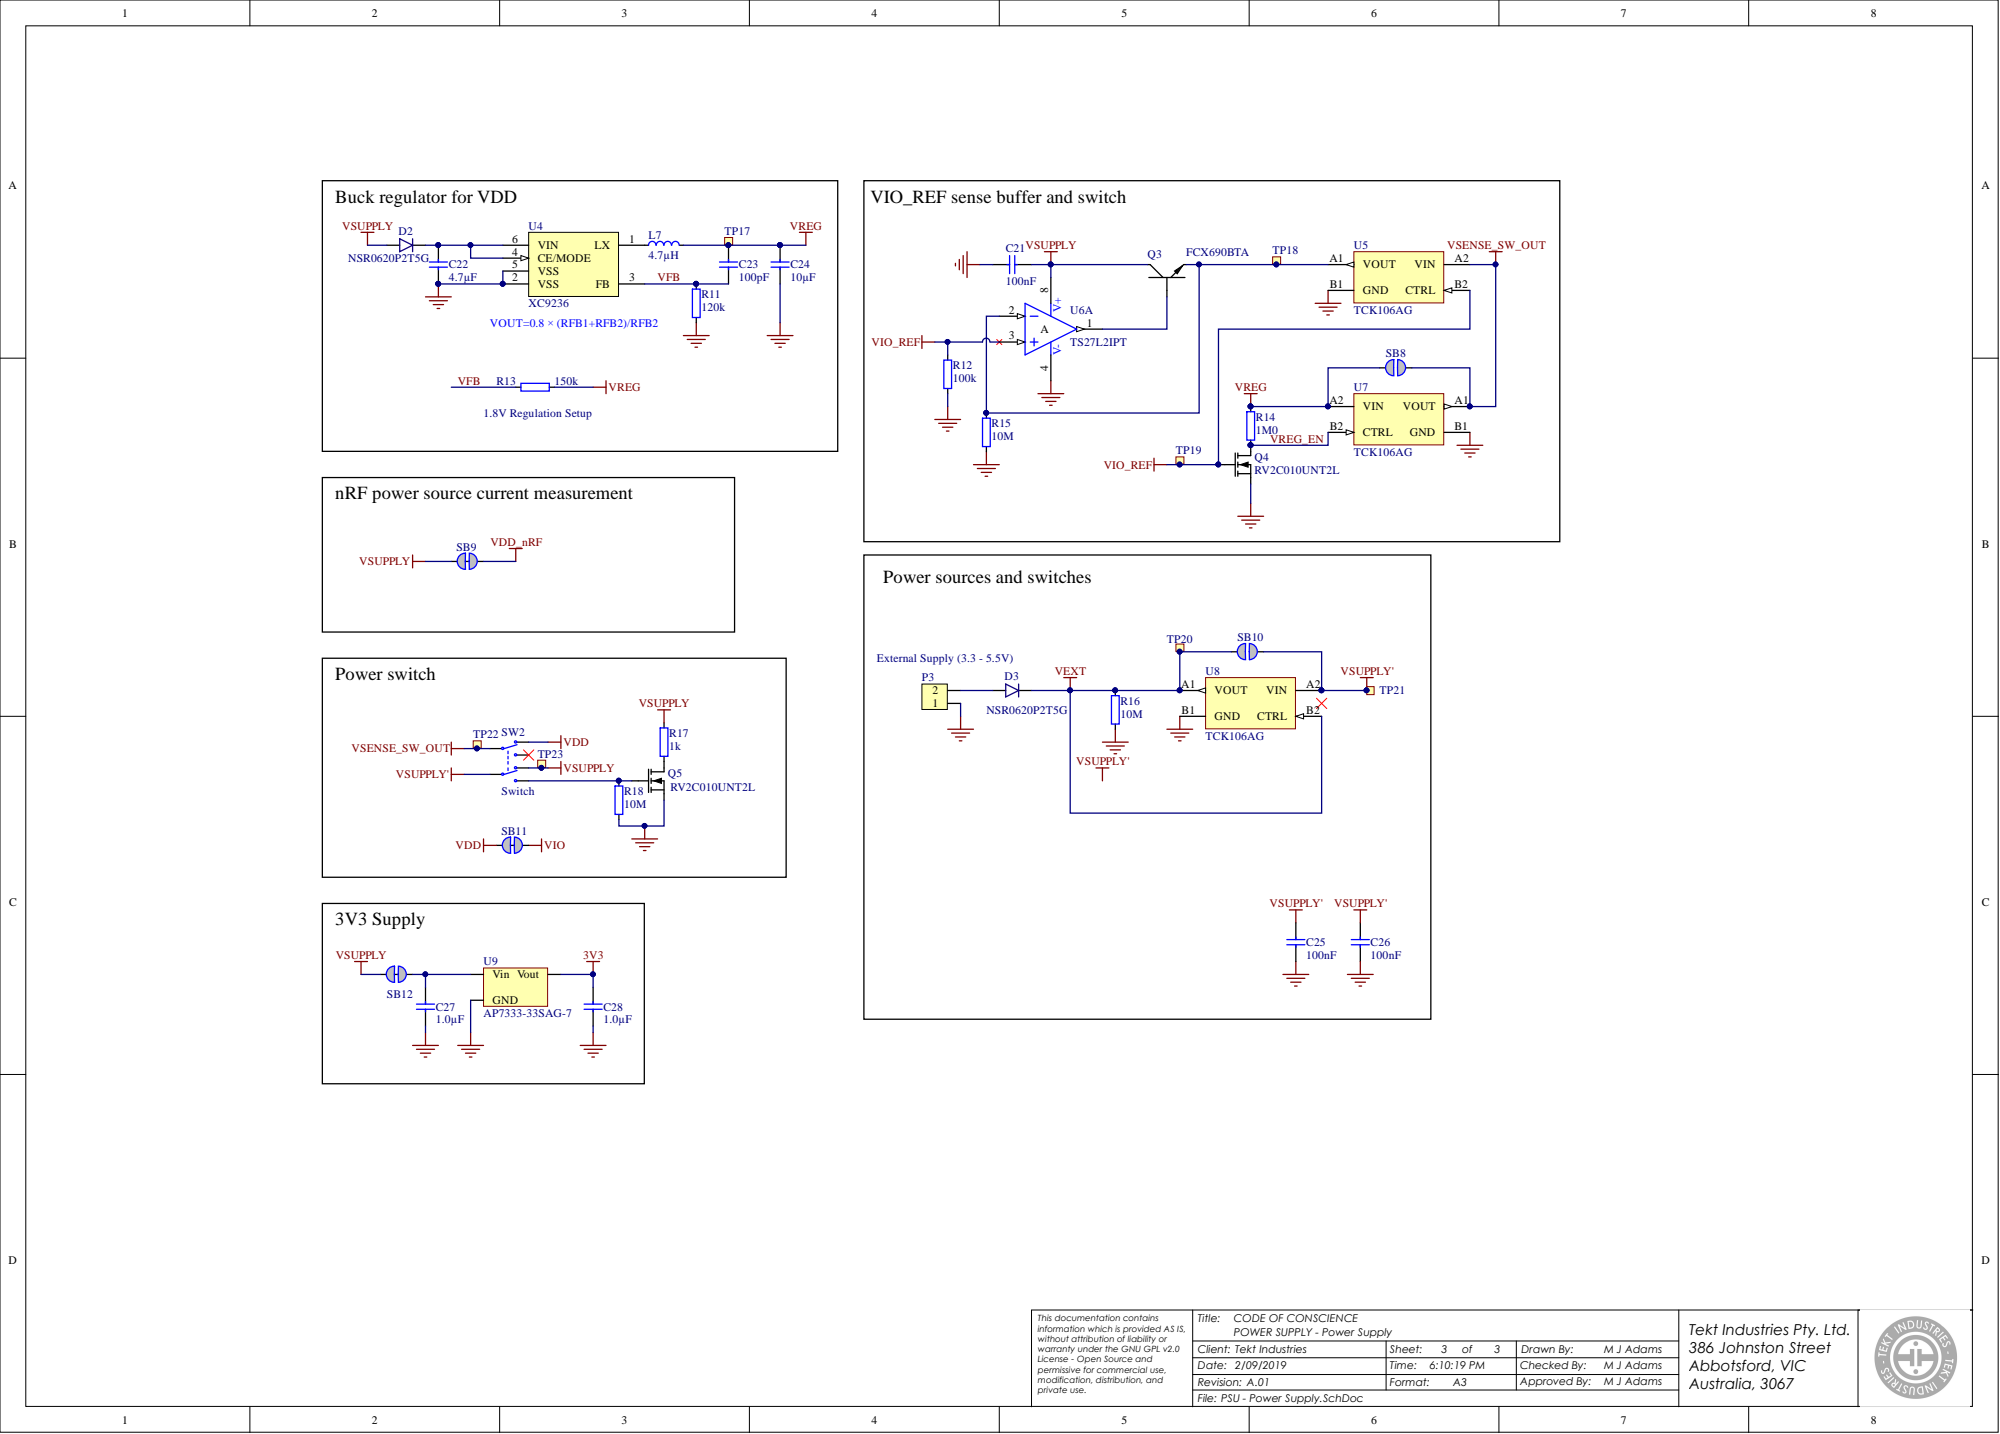
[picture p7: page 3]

Buck regulator for VDD

VIO_REF sense buffer and switch

nRF power source current measurement

Power sources and switches

This documentation contains information which is provided AS IS, without attribution of liability or warranty under the GNU GPL v2.0 License - Open Source and permissive for commercial use, modification, distribution, and private use. | Title: CODE OF CONSCIENCE POWER SUPPLY - Power Supply | Tekt Industries Pty. Ltd. 386 Johnston Street Abbotsford, VIC Australia, 3067

Client: Tekt Industries | Sheet: 3 of 3 | Drawn By: M J Adams
Date: 2/09/2019 | Time: 6:10:19 PM | Checked By: M J Adams
Revision: A.01 | Format: A3 | Approved By: M J Adams

PSU - Power Supply.SchDoc
